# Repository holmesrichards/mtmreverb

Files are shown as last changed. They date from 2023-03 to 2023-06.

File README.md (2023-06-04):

# Spring Reverb

This is a Kosmo format adaptation of the [Music Thing Modular Spring Reverb](https://www.musicthing.co.uk/Spring-Reverb/). (Which is open source, [Creative Commons Attribution-ShareAlike 3.0](https://creativecommons.org/licenses/by-sa/3.0/), so this project is too.)

# Circuit changes

Only very minor tweaks to the original circuit:

* Expansion module (consisting of a potentiometer and a pair of RCA jacks) incorporated into main module
* Single rail-to-rail bypass caps replaced with dual rail-to-ground
* Power reversal protection diodes added
* AC coupling capacitors C1, C2 changed from 10 µF electrolytic to 1 µF film
* Footprint for 100k resistor to ground on IN_2 (FEEDBACK) left in place but marked "OMIT?"

# Discussion

R5, the 100k to ground on input IN_2, is parallel to several other ~50k resistances to ground. This means the input impedance at IN_2 is much lower than the usual 100k. R5 only makes it even lower, and I see no reason why one would want to do that. I left the footprint for this resistor in place but marked it "OMIT?" on the silkscreen and left it out in my build. This resistor is not included in the BOM.

# Errata

* In the v1.0 circuit boards the solder jumper is bridged, not open, so it should be cut if using the brick and left alone if not (contrary to what the silkscreen implies). 

* In the v1.0 front panel the pads around the hole for the "To" phono jack make the jack contact ground. This is incorrect. Use nylon washers on both sides of the hole to isolate the jack, and make sure the hole isn't plated through. 

These errors are corrected in the post-v1.0 versions.

## Current draw

 mA +12 V,  mA -12 V
 
## Photos

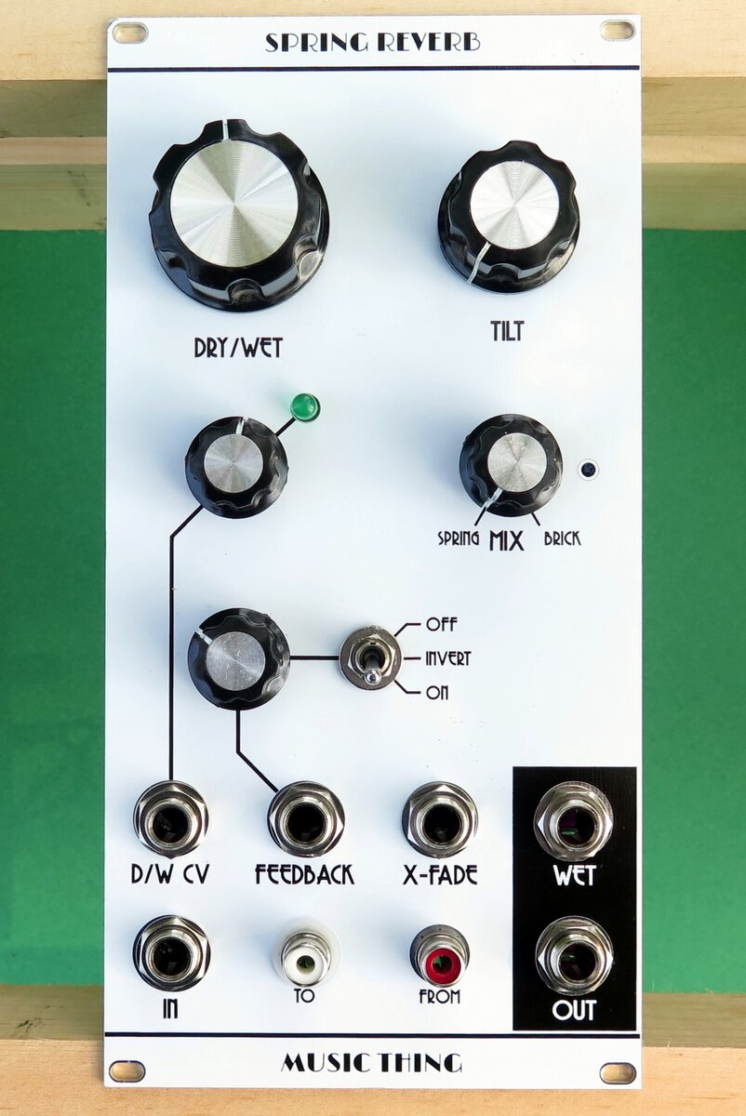
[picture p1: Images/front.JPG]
Front

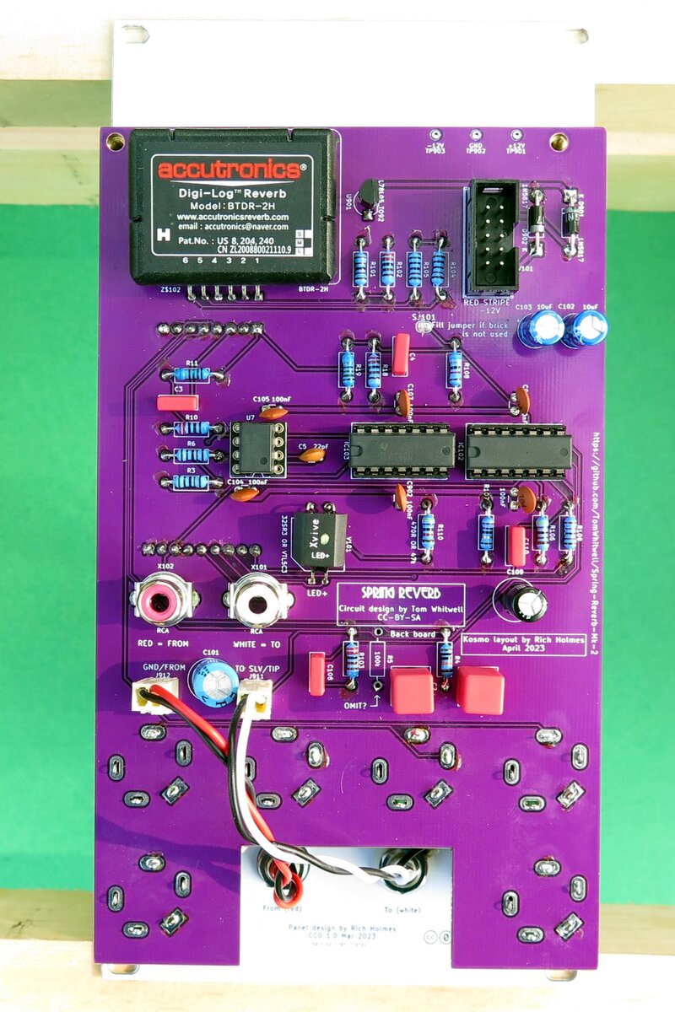
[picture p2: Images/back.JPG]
Back


## Documentation

* [Schematic](Docs/springReverbRev2_schematic.pdf)
* PCB layout: [front board front side](Docs/Layout/springReverbRev2_FrontPCB/springReverbRev2_FrontPCB_front.svg), [front board back side](Docs/Layout/springReverbRev2_FrontPCB/springReverbRev2_FrontPCB_back.svg), [back board front side](Docs/Layout/springReverbRev2_BackPCB/springReverbRev2_BackPCB_front.svg), [back board back side](Docs/Layout/springReverbRev2_BackPCB/springReverbRev2_BackPCB_back.svg)
* [BOM](Docs/BOM/springReverbRev2_bom.md)
* [Blog post](https://analogoutputblog.wordpress.com/2023/05/06/spring-has-sprung/)

## GitHub repository

* [https://github.com/holmesrichards/mtmreverb](https://github.com/holmesrichards/mtmreverb)

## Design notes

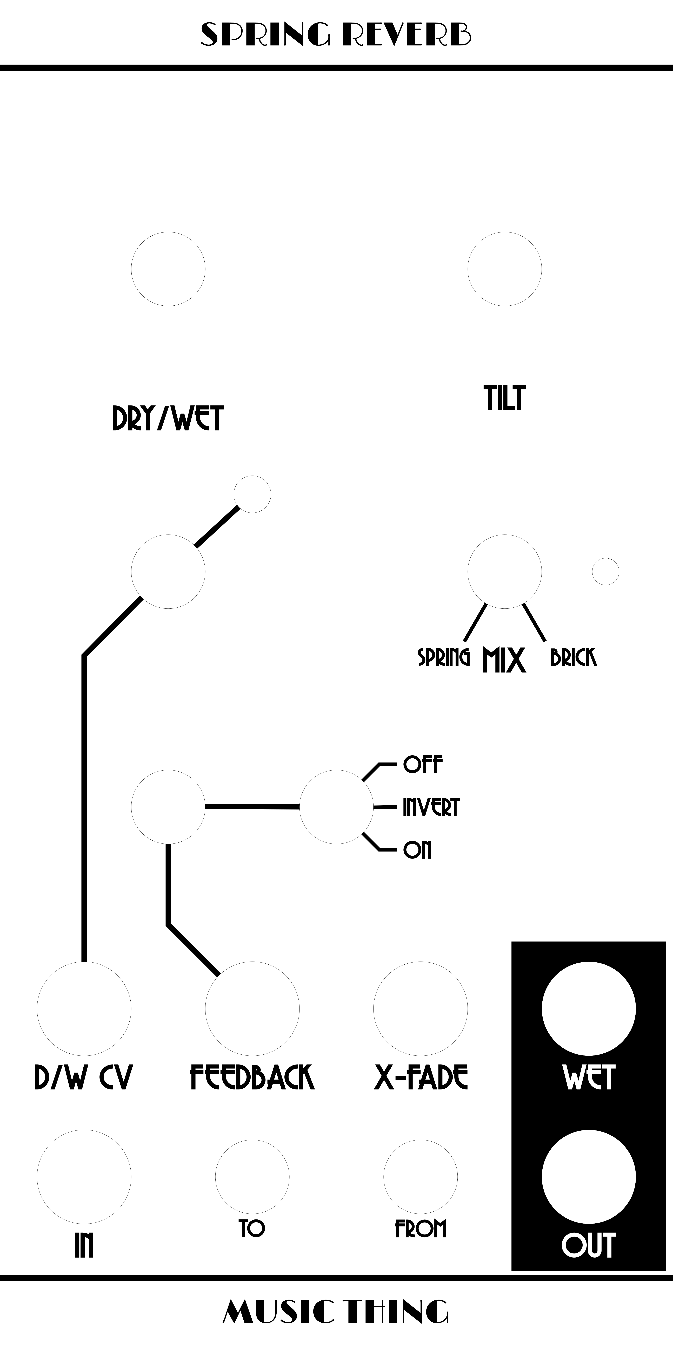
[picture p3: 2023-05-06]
Images/springreverb_panel_art.png

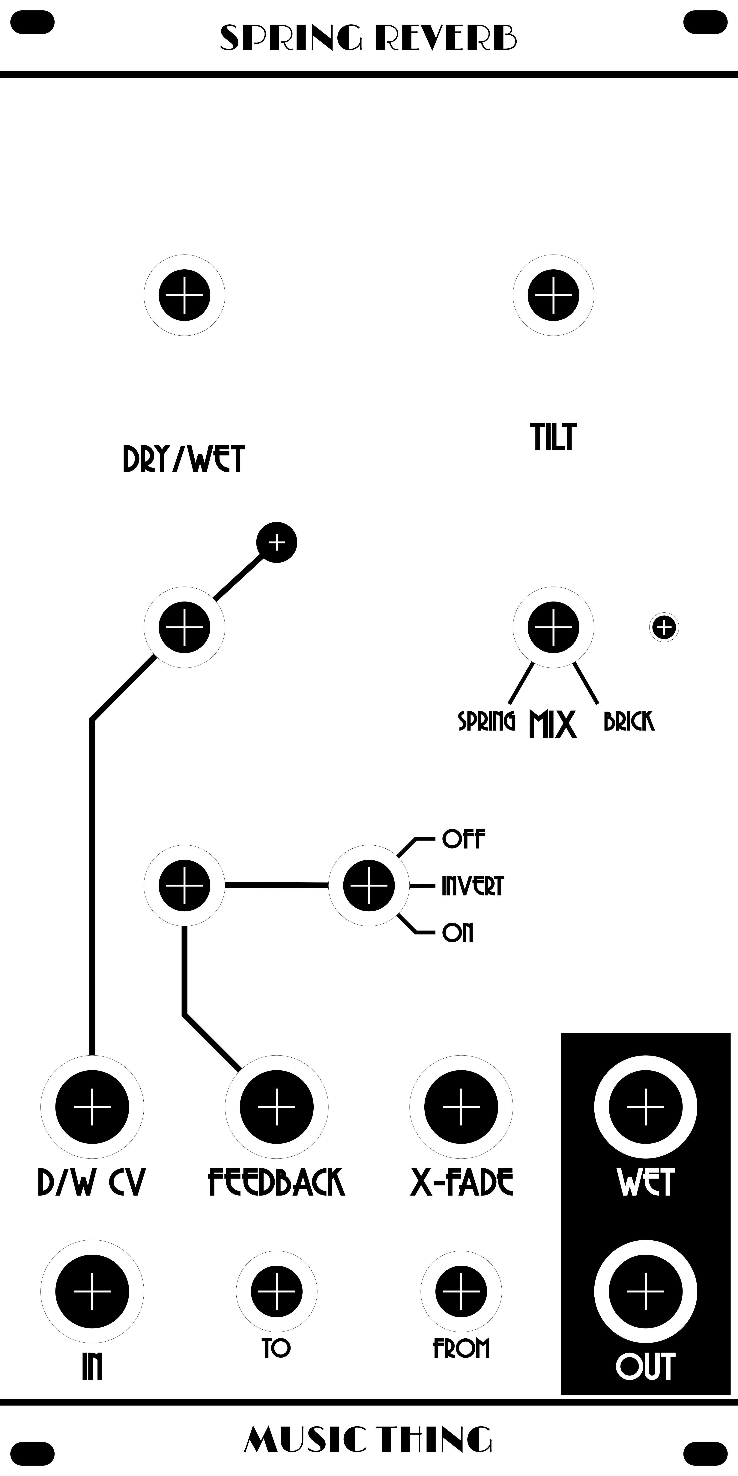
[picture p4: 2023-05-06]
Images/springreverb_panel_holes.png

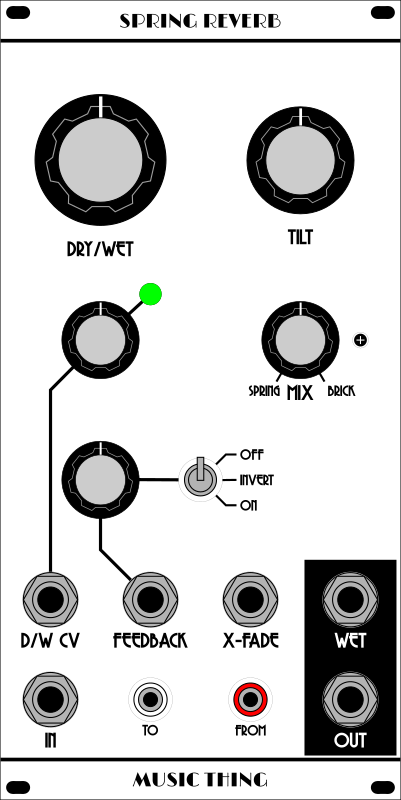
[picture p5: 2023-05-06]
Images/springreverb_panel.png

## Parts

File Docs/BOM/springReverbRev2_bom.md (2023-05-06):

# springReverbRev2.kicad_sch BOM

Fri 05 May 2023 09:01:19 PM EDT

Generated from schematic by Eeschema 7.0.2-6a45011f42~172~ubuntu22.04.1

**Component Count:** 108

| Refs | Qty | Component | Description | Manufacturer | Part | Vendor | SKU |
| ----- | --- | ---- | --- | ---- | ---- | ---- | ---- |
| C1, C2 | 2 | 1uF | Polyester film capacitor, 5 mm pitch |  |  | Tayda |  |
| C3, C4 | 2 | 33nF | Polyester film capacitor, 5 mm pitch |  |  | Tayda |  |
| C5 | 1 | 22pF | Ceramic capacitor, 2.5 mm pitch |  |  | Tayda |  |
| C6, C7, C104–107, C901–904 | 10 | 100nF | Ceramic capacitor, 2.5 mm pitch |  |  | Tayda |  |
| C101 | 1 | 10uF | Unpolarized electrolytic capacitor, 3.5 mm pitch |  |  | Tayda |  |
| C102, C103 | 2 | 10uF | Electrolytic capacitor, 2.5 mm pitch |  |  | Tayda | A-4349 |
| C108 | 1 | 3.3nF | Polyester film capacitor, 5 mm pitch |  |  | Tayda |  |
| C109 | 1 | 22uF | Unpolarized electrolytic capacitor, 3.5 mm pitch |  |  | Tayda |  |
| C110 | 1 | 2.2nF | Polyester film capacitor, 5 mm pitch |  |  | Tayda |  |
| D901, D902 | 2 | 1N5817 | Schottky Barrier Rectifier Diode, DO-41 |  |  | Tayda | A-159 |
| IC102, IC103 | 2 | TL074 | Quad operational amplifier, DIP-14 |  |  | Tayda | A-1138 |
| J901, J905 | 2 | AudioJack2_SwitchT | Audio Jack, 2 Poles (Mono / TS), Switched T Pole (Normalling) |  |  | Tayda | A-1121 |
| J902–904, J906 | 4 | AudioJack2 | Audio Jack, 2 Poles (Mono / TS) |  |  | Tayda | A-1121 |
| J907 | 1 | Conn_01x08_Socket | 2.54 mm pitch pin socket |  |  |  |  |
| J908 | 1 | Conn_01x08_Pin | 2.54 mm pitch pin header |  |  |  |  |
| J909 | 1 | Conn_01x09_Socket | 2.54 mm pitch pin socket |  |  |  |  |
| J910 | 1 | Conn_01x09_Pin | 2.54 mm pitch pin header |  |  |  |  |
| J911, J912 | 2 | 2_pin_Molex_header | KK254 Molex header |  |  | Tayda | A-804 |
| J913, J914 | 2 | 2_pin_Molex_connector | KK254 Molex connector |  |  | Tayda | A-826 |
| J915–917 | 3 | DIP-8 | 8 pin DIP socket |  |  |  |  |
| J918, J919 | 2 | DIP-14 | 14 pin DIP socket |  |  | Tayda | A-004 |
| LED1 | 1 | LED_green | Light emitting diode |  |  | Tayda | A-1553 |
| R1, R2, R7, R16, R20 | 5 | 47k | Resistor |  |  | Tayda |  |
| R3, R6, R104, R105 | 4 | 10k | Resistor |  |  | Tayda |  |
| R4, R8, R9, R12, R13, R21–23 | 8 | 100k | Resistor |  |  | Tayda |  |
| R10, R18, R24, R102, R103 | 5 | 2.2k | Resistor |  |  | Tayda |  |
| R11, R19 | 2 | 6.8k | Resistor |  |  | Tayda |  |
| R25, R101, R109 | 3 | 22k | Resistor |  |  | Tayda |  |
| R26 | 1 | 15k | Resistor |  |  | Tayda |  |
| R106 | 1 | 4.7k | Resistor |  |  | Tayda |  |
| R107 | 1 | 22R | Resistor |  |  | Tayda |  |
| R108 | 1 | 68k | Resistor |  |  | Tayda |  |
| R110 | 1 | 470R OR 47k | 470R for Silonex 32SR3, 47k for VTL5C3 |  |  | Tayda |  |
| RV901–903, RV905 | 4 | B50k | 16 mm potentiometer |  |  | Tayda |  |
| RV904 | 1 | B10k | 16 mm potentiometer |  |  | Tayda |  |
| SV101 | 1 | Synth_power_2x5 | Pin header 2.54 mm 2x5 |  |  | Tayda | A-2939 |
| SW901 | 1 | SW_SPDT_MSM | Switch, single pole double throw, center OFF position |  |  | Tayda | A-3187 |
| U1, U2 | 2 | TL072 | Dual operational amplifier, DIP-8 |  |  | Tayda | A-037 |
| U7 | 1 | NE5532 | Dual Low-Noise Operational Amplifiers, DIP-8/SOIC-8 |  |  |  |  |
| U901 | 1 | L78L05_TO92 | Positive 100mA 30V Linear Regulator, Fixed Output 5V, TO-92 |  |  | Tayda | A-176 |
| V101 | 1 | 32SR3 OR VTL5C3 | Low Cost Axial Vactrols |  |  |  |  |
| VR1 | 1 | 10k | Trim potentiometer | Bourns | 3362P | Tayda |  |
| X101 | 1 | RCA | Audio Jack, 2 Poles (Mono / TS) | CUI | RCJ-023 | Digi-Key | CP-1408-ND |
| X102 | 1 | RCA | Audio Jack, 2 Poles (Mono / TS) | CUI | RCJ-022 | Digi-Key | CP-1407-ND |
| X103 | 1 | RCA | Audio Jack, 2 Poles (Mono / TS) | Switchcraft | BPJF03X | Digi-Key | SC2441-ND |
| X104 | 1 | RCA | Audio Jack, 2 Poles (Mono / TS) | Switchcraft | BPJF02X | Digi-Key | SC2439-ND |
| Z$102 | 1 | BTDR-2H | Medium Decay Reverb Module | Belton Accutronics | BTDR-2H |  |  |
| ZKN901 | 1 | Knob_MF-A04 | MF-A04 knob |  |  |  |  |
| ZKN902 | 1 | Knob_MF-A03 | MF-A03 knob |  |  |  |  |
| ZKN903–905 | 3 | Knob_MF-A01 | MF-A01 knob |  |  |  |  |
| ZSC901–904 | 4 | Screw | M3 6 mm screw |  |  |  |  |
| ZSP901, ZSP902 | 2 | Spacer | M3 10 mm FF spacer |  |  |  |  |
| ZWA901, ZWA902 | 2 | Washer | M3 washer |  |  |  |  |

## Resistors in color band order
|Value|Qty|Refs|
|----|----|----|
|10k|4|R3, R6, R104, R105|
|100k|8|R4, R8, R9, R12, R13, R21–23|
|15k|1|R26|
|22R|1|R107|
|2.2k|5|R10, R18, R24, R102, R103|
|22k|3|R25, R101, R109|
|4.7k|1|R106|
|47k|5|R1, R2, R7, R16, R20|
|6.8k|2|R11, R19|
|68k|1|R108|
|470R OR 47k|1|R110|

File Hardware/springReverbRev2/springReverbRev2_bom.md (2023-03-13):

# springReverbRev2.kicad_sch BOM

Wed 08 Mar 2023 10:55:59 PM EST

Generated from schematic by Eeschema 7.0.0-da2b9df05c~171~ubuntu22.04.1

**Component Count:** 109

| Refs | Qty | Component | Description | Manufacturer | Part | Vendor | SKU |
| ----- | --- | ---- | --- | ---- | ---- | ---- | ---- |
| C1, C2, C101 | 3 | 10uF | Unpolarized electrolytic capacitor |  |  | Tayda |  |
| C3, C4 | 2 | 33nF | Polyester film capacitor |  |  | Tayda |  |
| C5 | 1 | 22pF | Ceramic capacitor |  |  | Tayda |  |
| C6, C7, C104–107, C901–904 | 10 | 100nF | Ceramic capacitor |  |  | Tayda |  |
| C102, C103 | 2 | 10uF | Electrolytic capacitor, 2.5 mm pitch |  |  | Tayda | A-4349 |
| C108 | 1 | 3.3nF | Polyester film capacitor |  |  | Tayda |  |
| C109 | 1 | 22uF | Unpolarized electrolytic capacitor |  |  | Tayda |  |
| C110 | 1 | 2.2nF | Polyester film capacitor |  |  | Tayda |  |
| D901, D902 | 2 | 1N5817 | Schottky Barrier Rectifier Diode, DO-41 |  |  | Tayda | A-159 |
| IC102, IC103 | 2 | TL074 | Quad operational amplifier, DIP-14 |  |  | Tayda | A-1138 |
| J901, J905 | 2 | AudioJack2_SwitchT | Audio Jack, 2 Poles (Mono / TS), Switched T Pole (Normalling) |  |  | Tayda | A-1121 |
| J902–904, J906 | 4 | AudioJack2 | Audio Jack, 2 Poles (Mono / TS) |  |  | Tayda | A-1121 |
| J907 | 1 | Conn_01x08_Socket | Generic connector, single row, 01x08, script generated |  |  |  |  |
| J908 | 1 | Conn_01x08_Pin | Generic connector, single row, 01x08, script generated |  |  |  |  |
| J909 | 1 | Conn_01x09_Socket | Generic connector, single row, 01x09, script generated |  |  |  |  |
| J910 | 1 | Conn_01x09_Pin | Generic connector, single row, 01x09, script generated |  |  |  |  |
| J911, J912 | 2 | 2_pin_Molex_header | KK254 Molex header |  |  | Tayda | A-804 |
| J913, J914 | 2 | 2_pin_Molex_connector | KK254 Molex connector |  |  | Tayda | A-826 |
| J915–917 | 3 | DIP-8 | 8 pin DIP socket |  |  |  |  |
| J918, J919 | 2 | DIP-14 | 14 pin DIP socket |  |  |  |  |
| LED1 | 1 | LED_green | Light emitting diode |  |  | Tayda | A-1553 |
| R1, R2, R7, R16, R20 | 5 | 47k | Resistor |  |  | Tayda |  |
| R3, R6, R104, R105 | 4 | 10k | Resistor |  |  | Tayda |  |
| R8, R9, R12, R13, R21–23, R901, R902 | 9 | 100k | Resistor |  |  | Tayda |  |
| R10, R18, R24, R102, R103 | 5 | 2.2k | Resistor |  |  | Tayda |  |
| R11, R19 | 2 | 6.8k | Resistor |  |  | Tayda |  |
| R25, R101, R109 | 3 | 22k | Resistor |  |  | Tayda |  |
| R26 | 1 | 15k | Resistor |  |  | Tayda |  |
| R106 | 1 | 4.7k | Resistor |  |  | Tayda |  |
| R107 | 1 | 22R | Resistor |  |  | Tayda |  |
| R108 | 1 | 68k | Resistor |  |  | Tayda |  |
| R110 | 1 | 470R OR 47k | Resistor |  |  | Tayda |  |
| RV901–903, RV905 | 4 | B50k | Potentiometer |  |  | Tayda |  |
| RV904 | 1 | B10k | Potentiometer |  |  | Tayda |  |
| SV101 | 1 | Synth_power_2x5 | Pin header 2.54 mm 2x5 |  |  | Tayda | A-2939 |
| SW901 | 1 | SW_SPDT_MSM | Switch, single pole double throw, center OFF position |  |  | Tayda | A-3187 |
| U1, U2 | 2 | TL072 | Dual operational amplifier, DIP-8 |  |  | Tayda | A-037 |
| U7 | 1 | NE5532 | Dual Low-Noise Operational Amplifiers, DIP-8/SOIC-8 |  |  |  |  |
| U901 | 1 | L78L05_TO92 | Positive 100mA 30V Linear Regulator, Fixed Output 5V, TO-92 |  |  | Tayda | A-176 |
| V101 | 1 | 32SR3 OR VTL5C3 | Low Cost Axial Vactrols |  |  |  |  |
| VR1 | 1 | 10k | Trim-potentiometer |  |  | Tayda |  |
| X101 | 1 | RCA | Audio Jack, 2 Poles (Mono / TS) | CUI | RCJ-023 | Digi-Key | CP-1408-ND |
| X102 | 1 | RCA | Audio Jack, 2 Poles (Mono / TS) | CUI | RCJ-022 | Digi-Key | CP-1407-ND |
| X103 | 1 | RCA | Audio Jack, 2 Poles (Mono / TS) | Switchcraft | BPJF03X | Digi-Key | SC2441-ND |
| X104 | 1 | RCA | Audio Jack, 2 Poles (Mono / TS) | Switchcraft | BPJF02X | Digi-Key | SC2439-ND |
| Z$102 | 1 | BTDR-2H |  |  |  |  |  |
| ZKN901 | 1 | Knob_MF-A04 | MF-A04 knob |  |  |  |  |
| ZKN902 | 1 | Knob_MF-A03 | MF-A03 knob |  |  |  |  |
| ZKN903–905 | 3 | Knob_MF-A01 | MF-A01 knob |  |  |  |  |
| ZSC901–904 | 4 | Screw | M3 6 mm screw |  |  |  |  |
| ZSP901, ZSP902 | 2 | Spacer | M3 10 mm FF spacer |  |  |  |  |
| ZWA901, ZWA902 | 2 | Washer | M3 washer |  |  |  |  |

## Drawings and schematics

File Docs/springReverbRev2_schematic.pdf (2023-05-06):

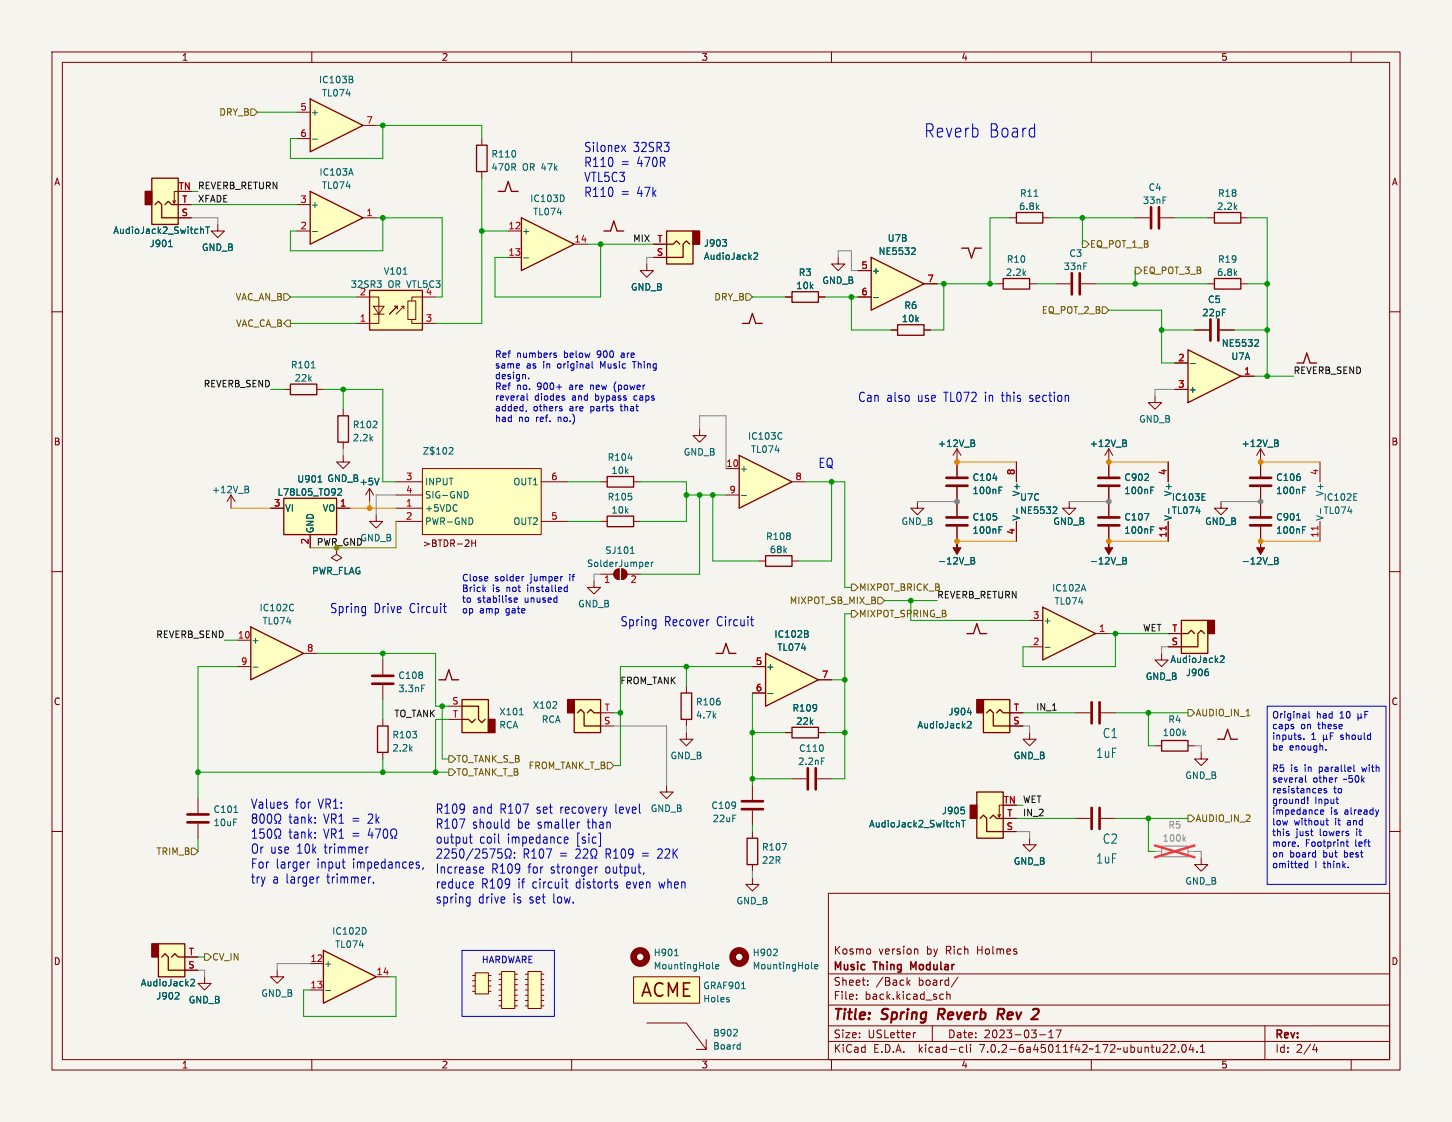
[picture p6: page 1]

op amp gate Ref numbers below 900 are

design. Ref no. 900+ are new (power

reveral diodes and bypass caps added, others are parts that had no ref. no.)

Close solder jumper if Brick is not installed

several other ~50k
ground! Input
low without it and

Values for VR1:
þÿ800©tank: VR1 = 2k
þÿ150©tank: VR1 = þÿ470©
Or use 10k trimmer
For larger input impedances,

R109 and R107 set recovery level
R107 should be smaller than
output coil impedance [sic]
Increase R109 for stronger output,
reduce R109 if circuit distorts even when
spring drive is set low.

Id: 2/4 Title: Spring Reverb Rev 2

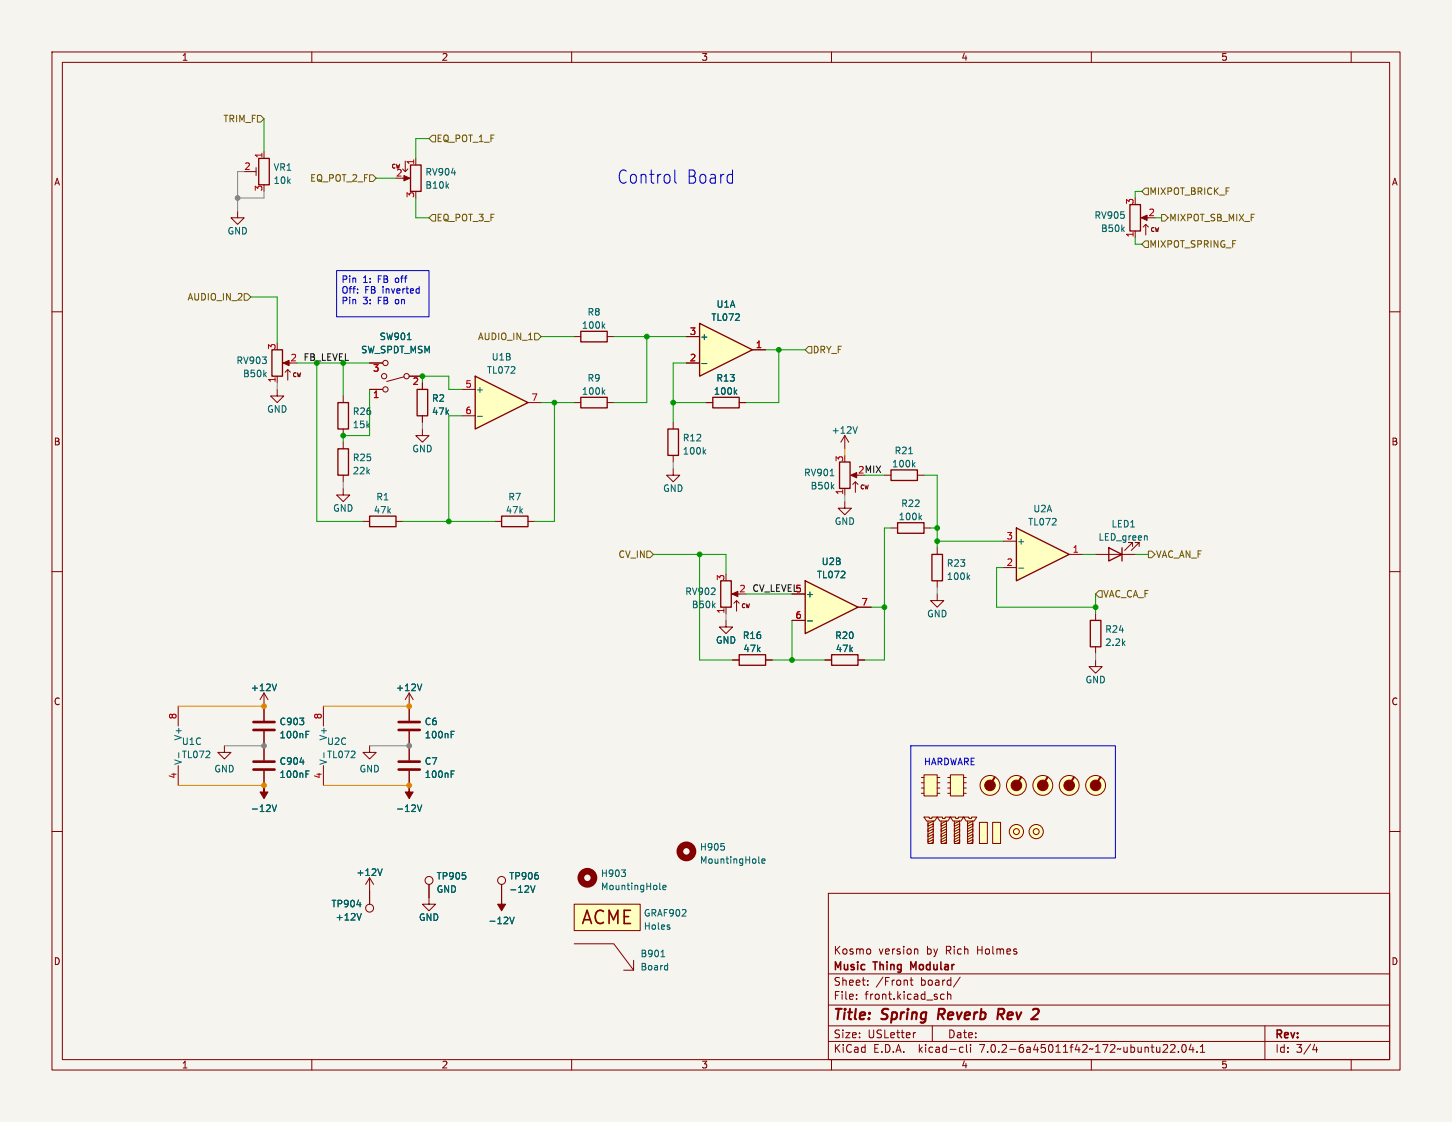
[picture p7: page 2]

Id: 3/4 Title: Spring Reverb Rev 2

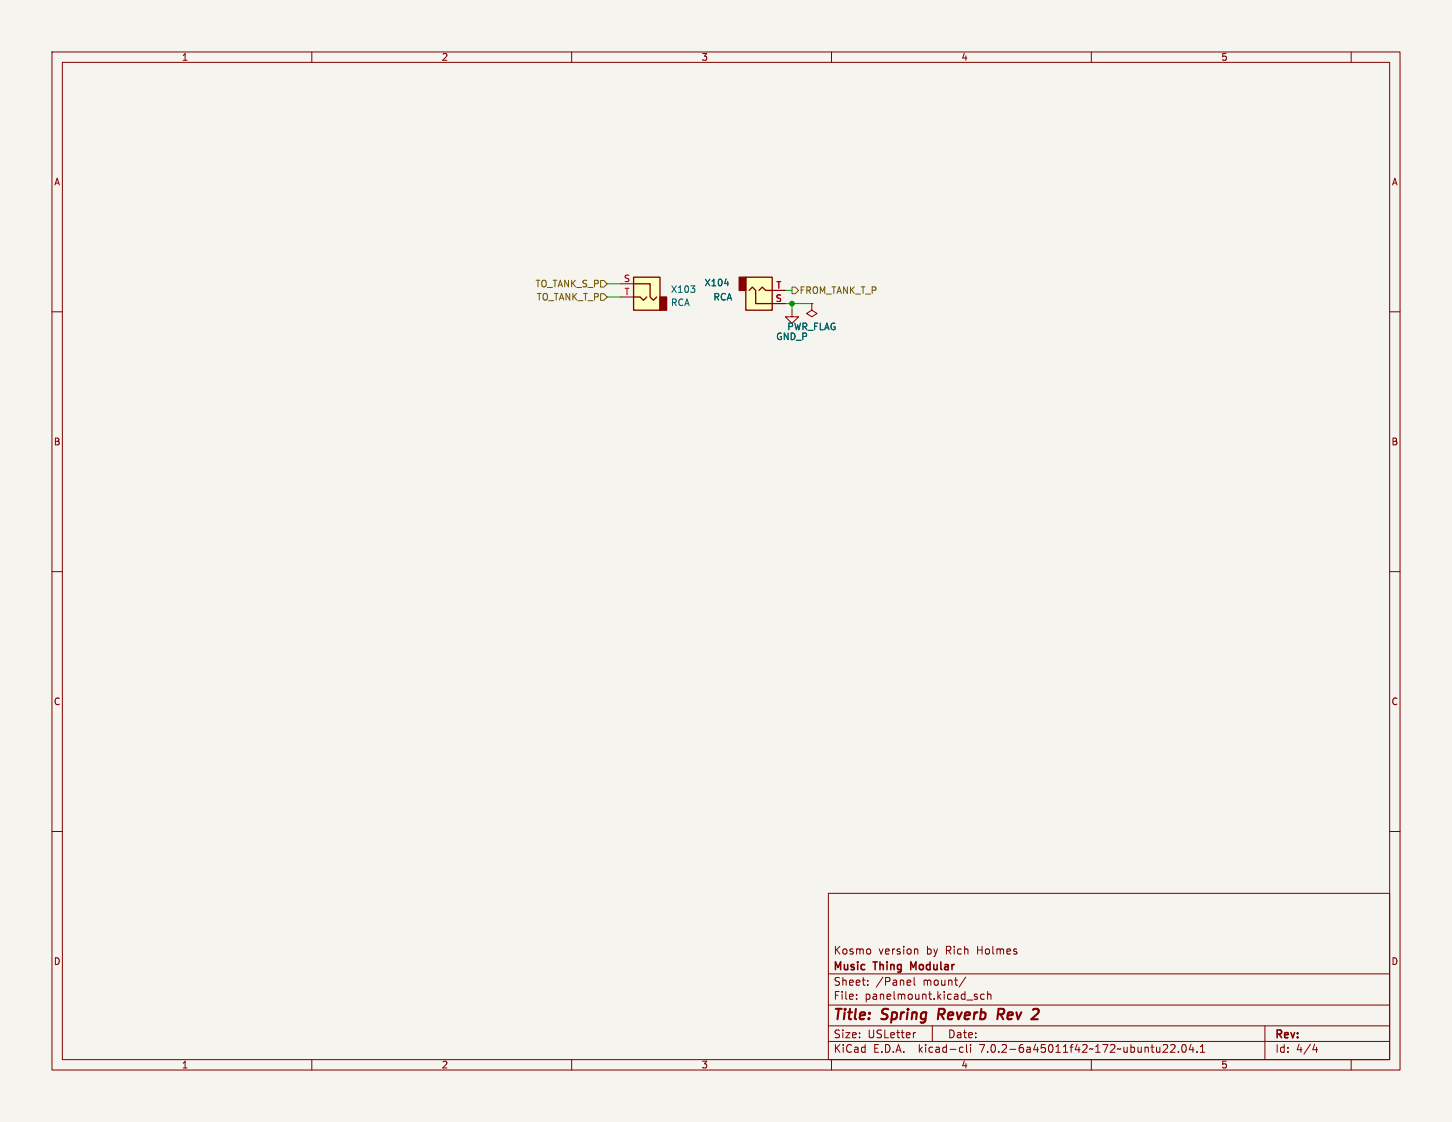
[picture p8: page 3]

Id: 4/4 Title: Spring Reverb Rev 2

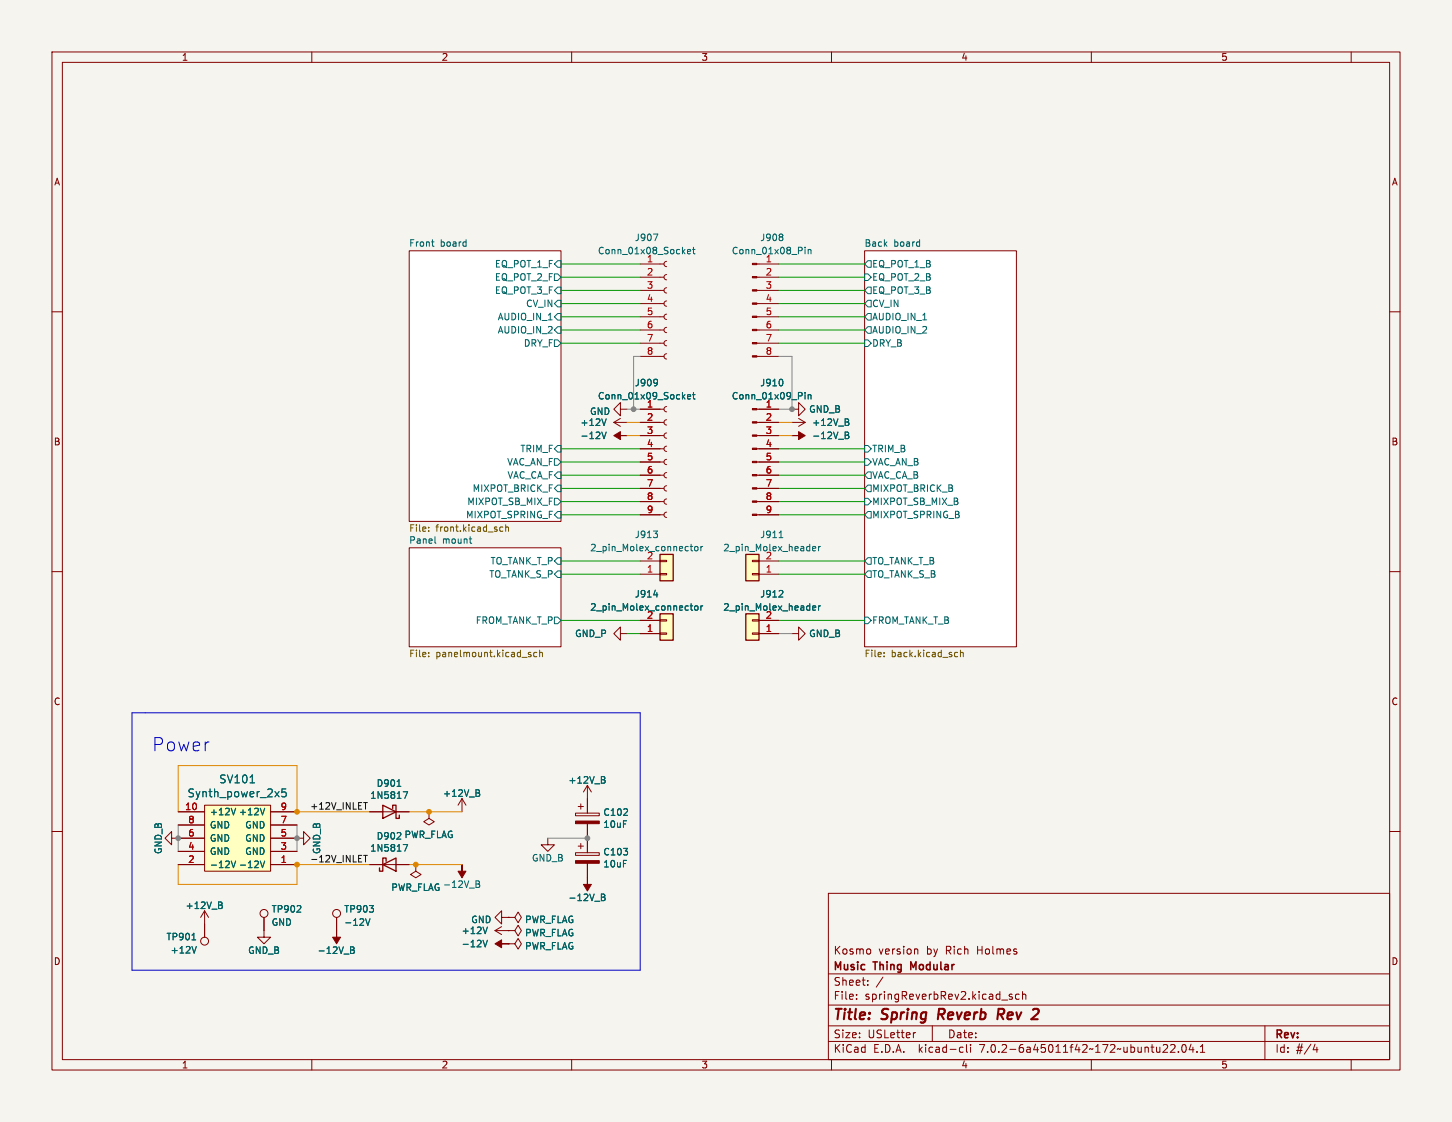
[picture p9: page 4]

Back board File: back.kicad_sch TO_TANK_S_P

Panel mount File: panelmount.kicad_sch

Id: #/4 Title: Spring Reverb Rev 2

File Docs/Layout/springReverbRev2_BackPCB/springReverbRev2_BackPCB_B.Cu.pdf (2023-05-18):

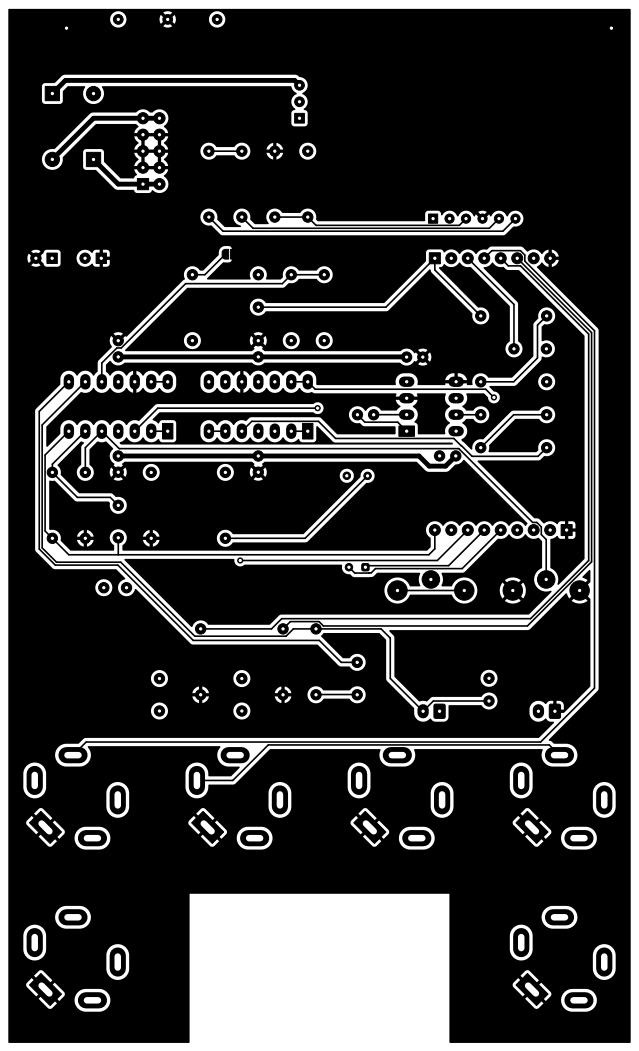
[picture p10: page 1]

Id: 1/1 Title: Spring Reverb Rev 2

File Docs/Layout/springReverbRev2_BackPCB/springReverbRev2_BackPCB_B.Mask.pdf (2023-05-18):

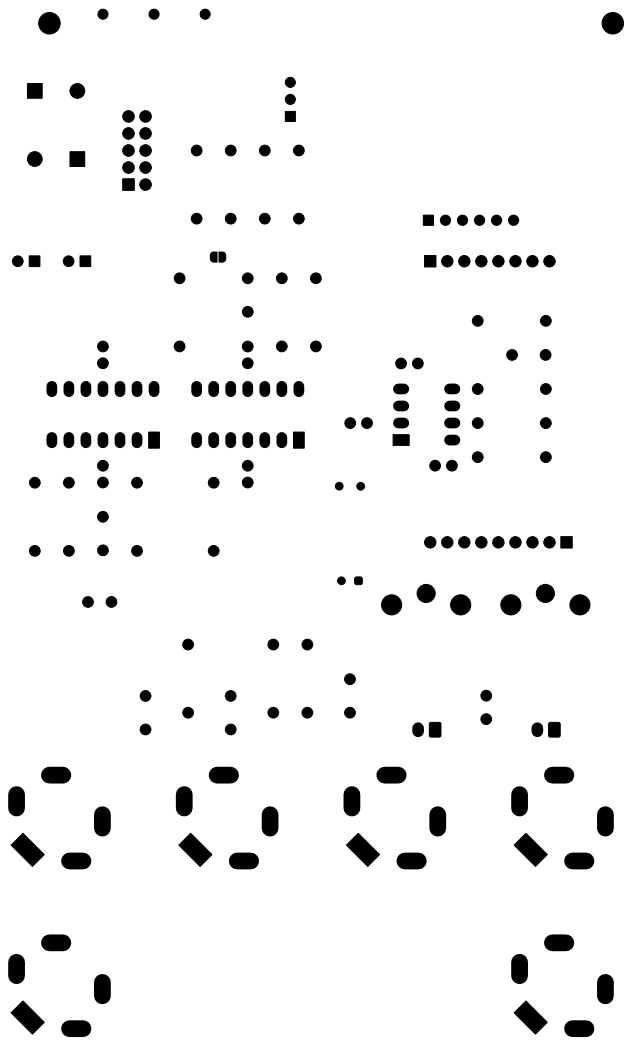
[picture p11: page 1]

Id: 1/1 Title: Spring Reverb Rev 2

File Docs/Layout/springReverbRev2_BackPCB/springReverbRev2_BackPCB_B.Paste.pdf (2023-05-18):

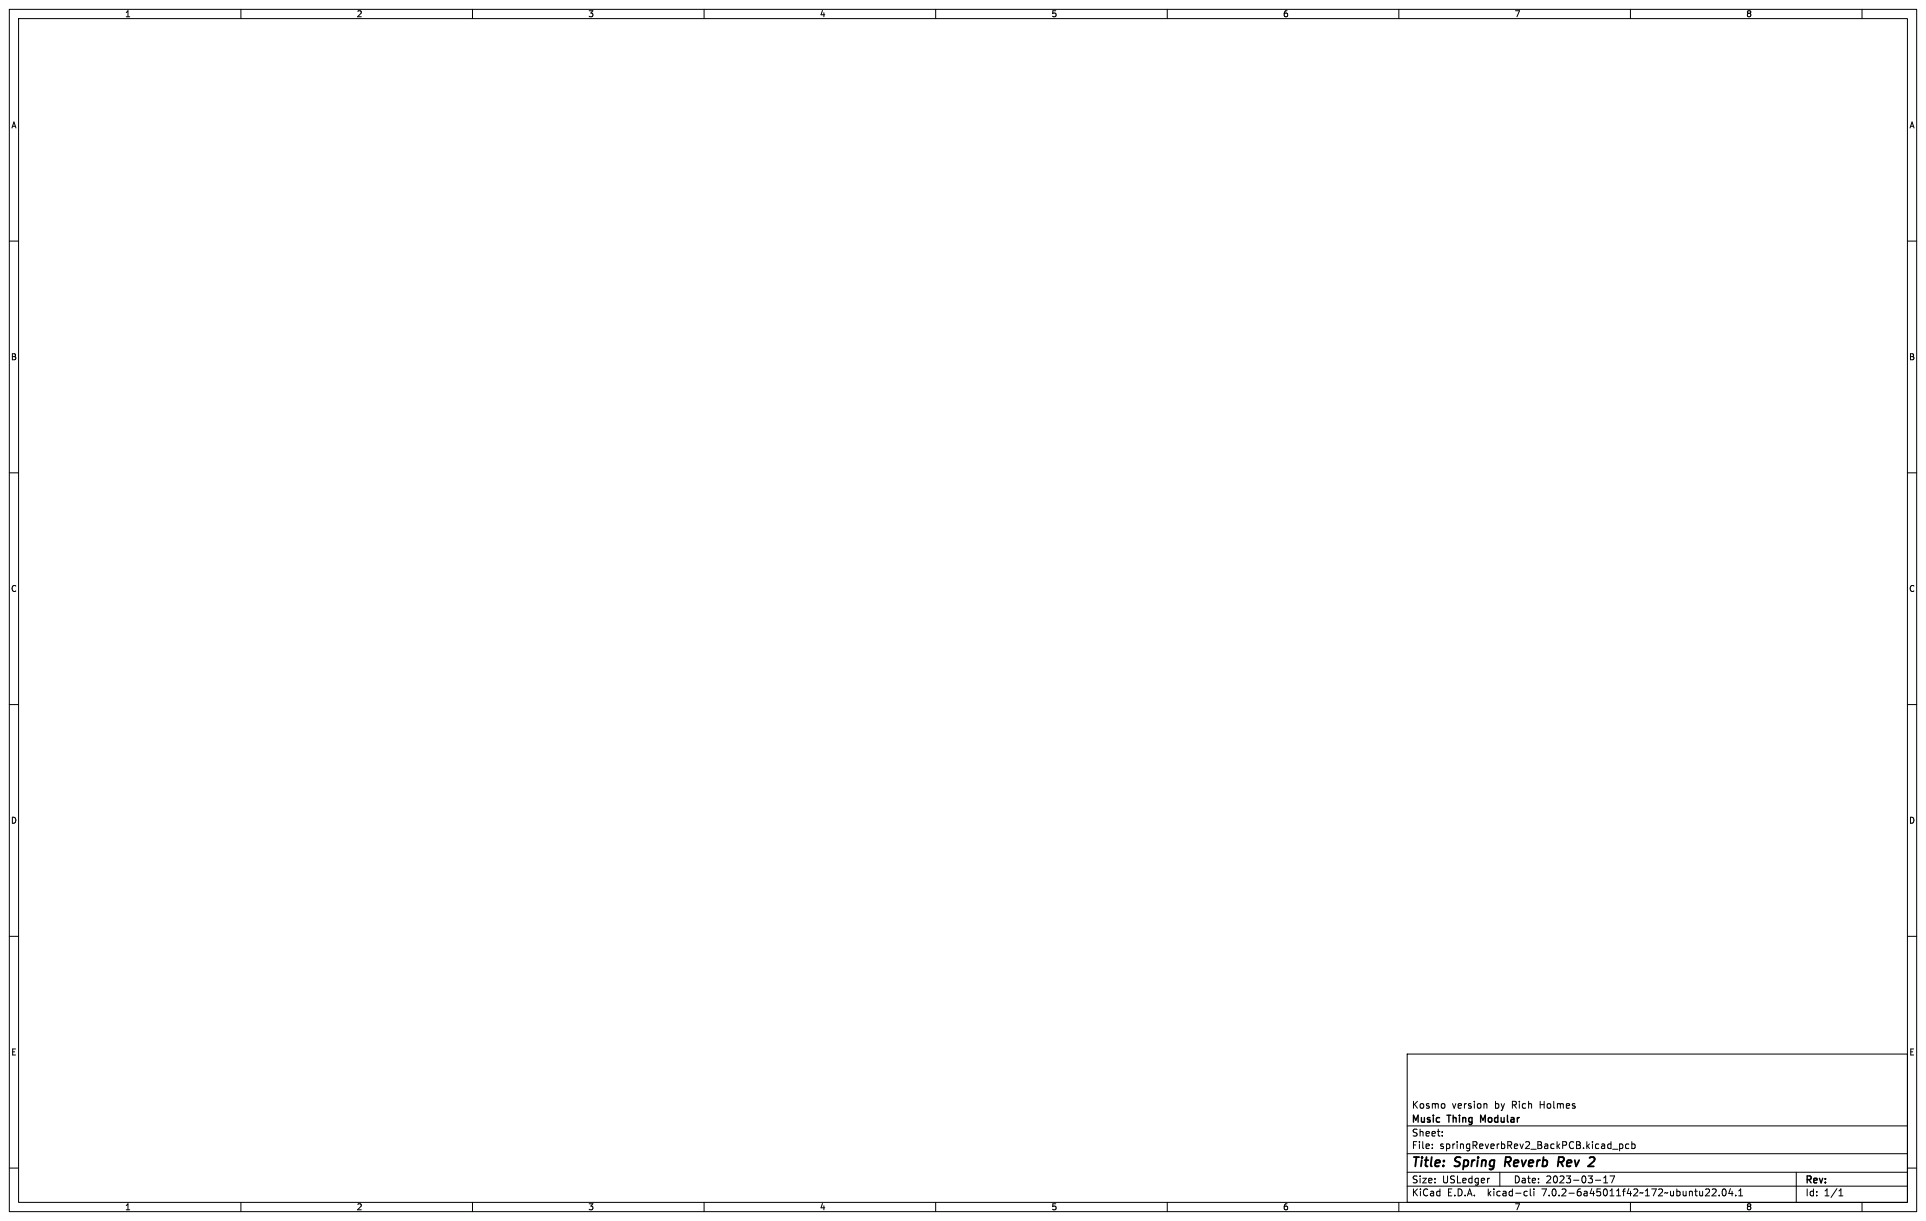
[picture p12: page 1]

Id: 1/1 Title: Spring Reverb Rev 2

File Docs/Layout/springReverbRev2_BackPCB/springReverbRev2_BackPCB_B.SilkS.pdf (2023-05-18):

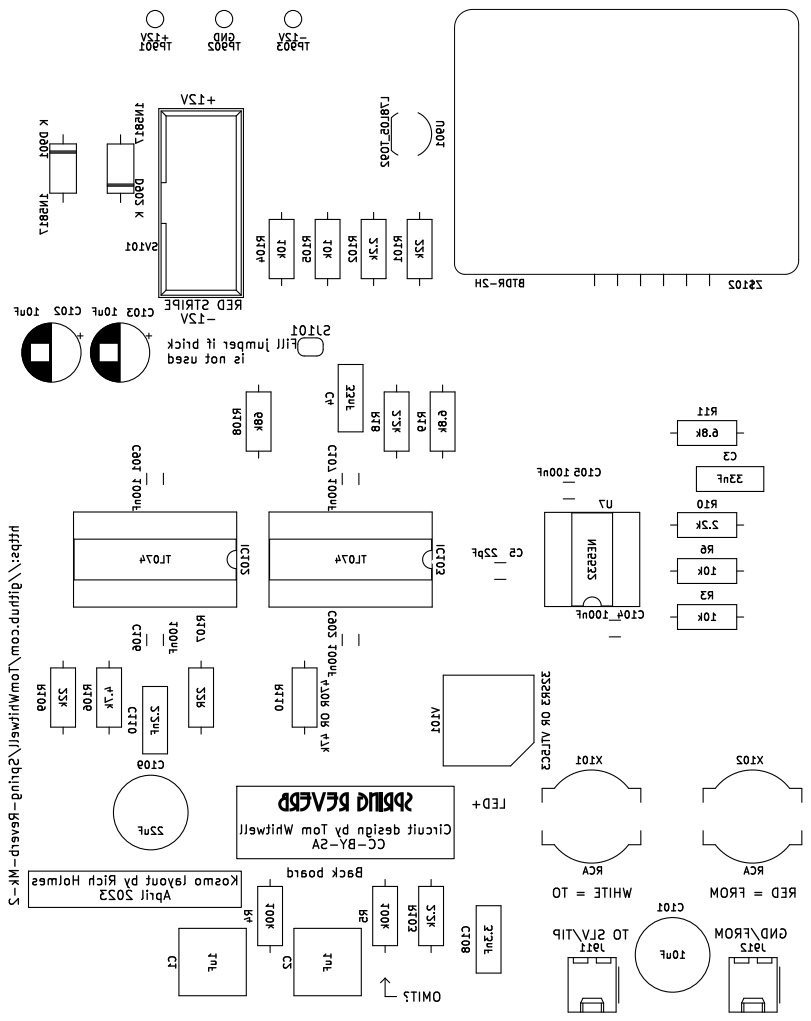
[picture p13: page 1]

Fill jumper if brick

Id: 1/1 Title: Spring Reverb Rev 2

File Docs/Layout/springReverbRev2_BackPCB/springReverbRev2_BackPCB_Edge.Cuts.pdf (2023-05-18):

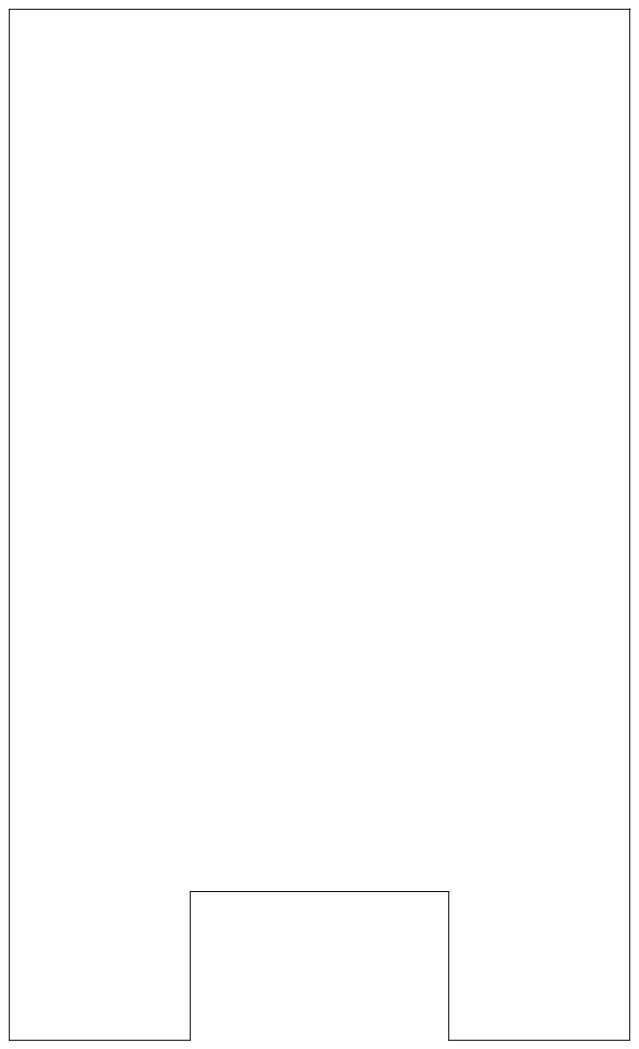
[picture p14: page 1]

Id: 1/1 Title: Spring Reverb Rev 2

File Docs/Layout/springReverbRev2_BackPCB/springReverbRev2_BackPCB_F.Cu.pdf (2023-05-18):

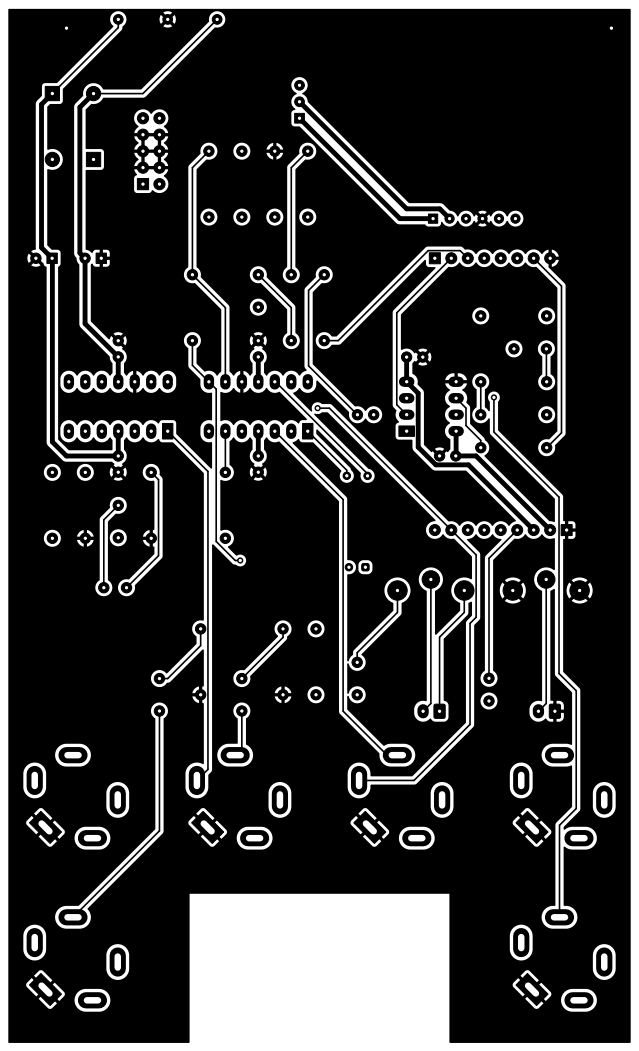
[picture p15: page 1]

Id: 1/1 Title: Spring Reverb Rev 2

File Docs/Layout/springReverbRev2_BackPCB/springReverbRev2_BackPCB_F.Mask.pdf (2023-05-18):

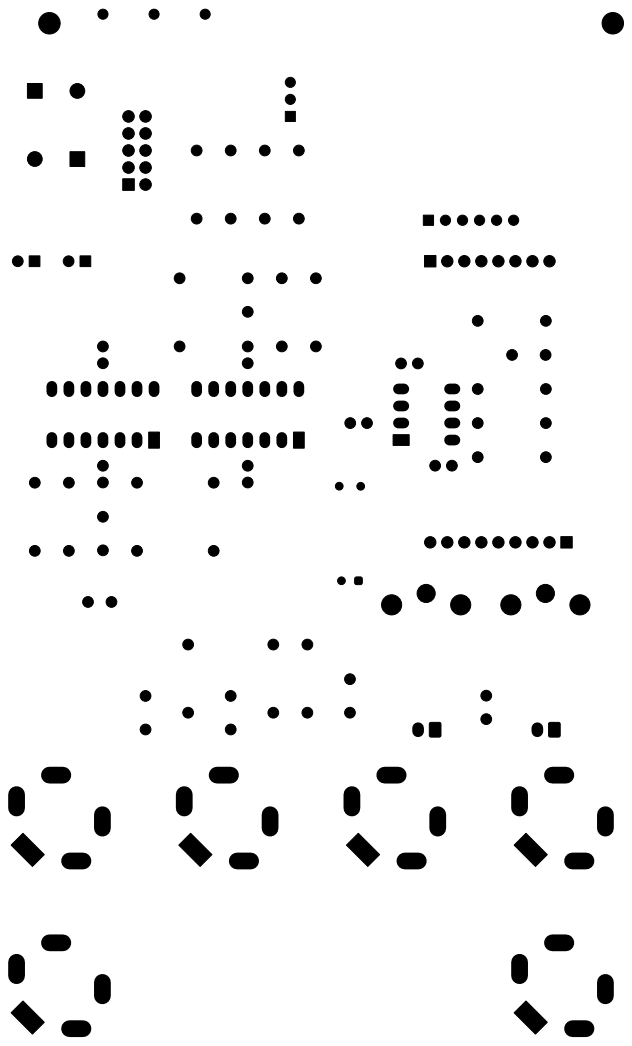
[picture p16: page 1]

Id: 1/1 Title: Spring Reverb Rev 2

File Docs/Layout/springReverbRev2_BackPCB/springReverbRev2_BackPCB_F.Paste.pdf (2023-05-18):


Id: 1/1 Title: Spring Reverb Rev 2

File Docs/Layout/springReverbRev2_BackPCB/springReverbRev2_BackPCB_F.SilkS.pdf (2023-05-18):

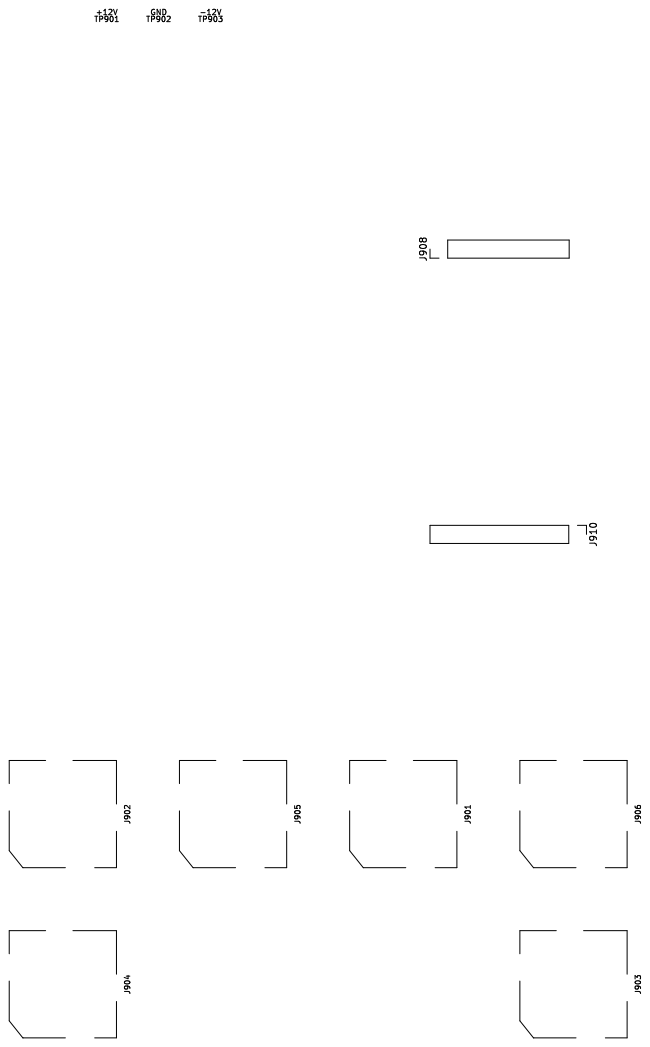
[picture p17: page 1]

Id: 1/1 Title: Spring Reverb Rev 2

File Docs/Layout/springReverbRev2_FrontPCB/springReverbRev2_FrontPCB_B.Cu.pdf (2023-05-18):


Id: 1/1 Title: Spring Reverb Rev 2

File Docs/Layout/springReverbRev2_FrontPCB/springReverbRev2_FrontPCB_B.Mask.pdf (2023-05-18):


Id: 1/1 Title: Spring Reverb Rev 2

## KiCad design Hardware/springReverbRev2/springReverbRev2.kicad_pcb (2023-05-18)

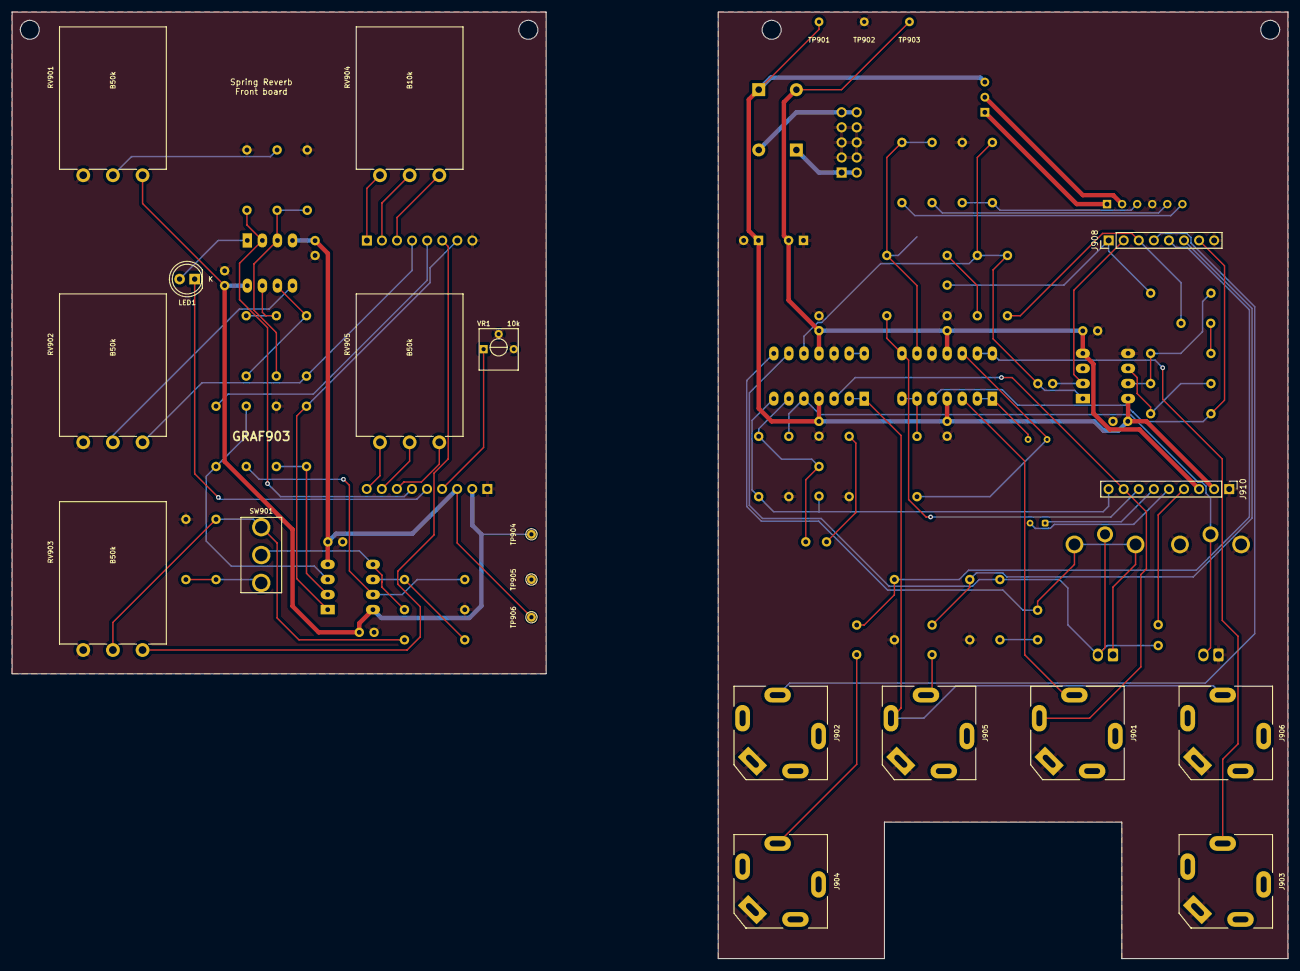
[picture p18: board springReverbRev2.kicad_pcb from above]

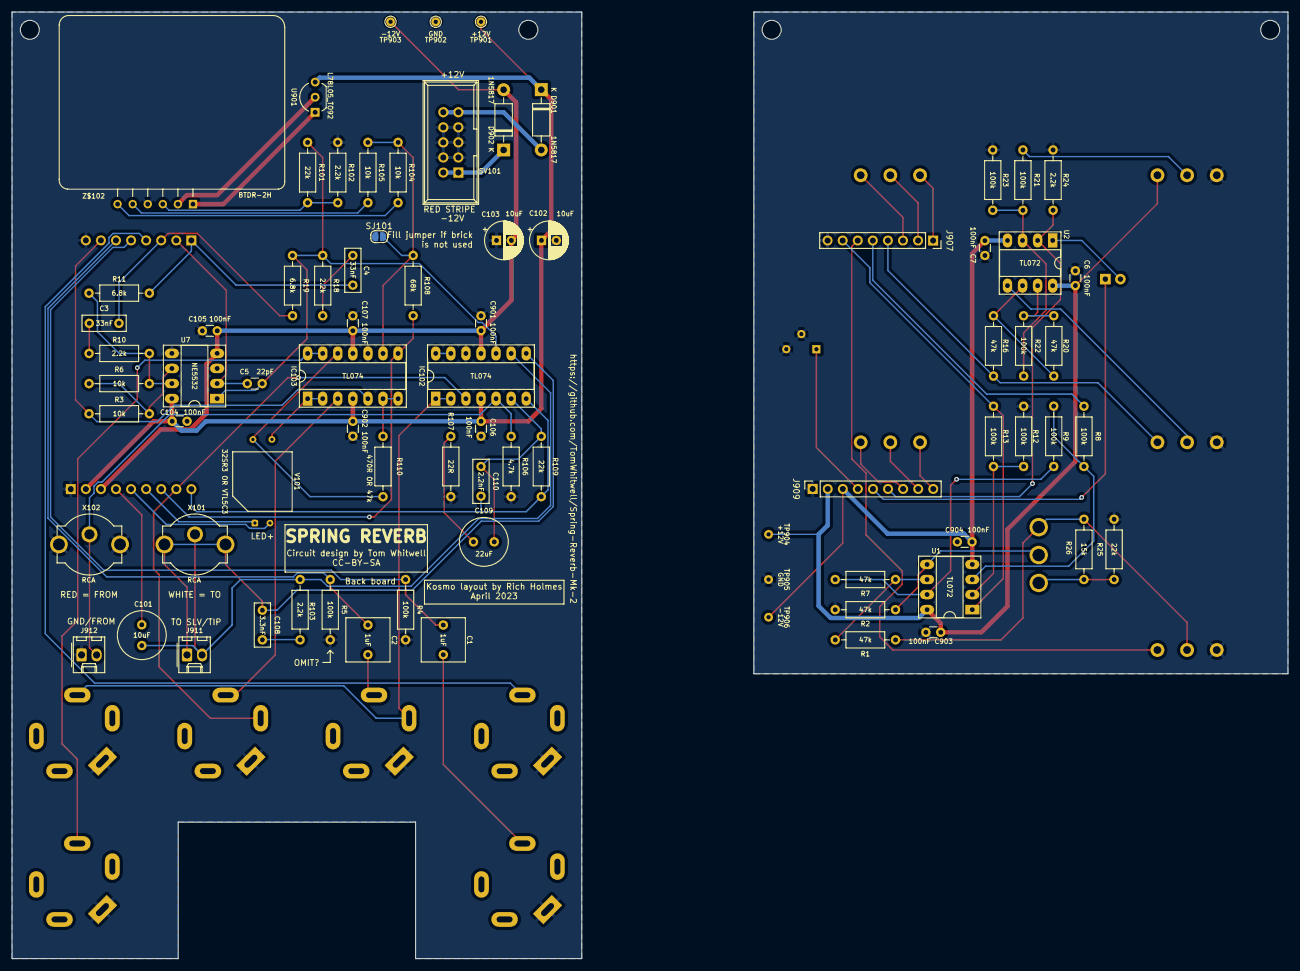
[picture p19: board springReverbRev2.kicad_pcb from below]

Board: 2 copper layers, 215.0 x 159.5 mm, 103 parts (75 on the bottom side), 73 nets.

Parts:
B901, B902: Board; Board_Marker
C1, C2: 1uF; C_Rect_L7.2mm_W7.2mm_P5.00mm_FKS2_FKP2_MKS2_MKP2
C3, C4: 33nF; C_Rect_L7.2mm_W2.5mm_P5.00mm_FKS2_FKP2_MKS2_MKP2
C5: 22pF; C_Disc_D3.0mm_W1.6mm_P2.50mm
C6, C7, C104, C105, C106, C107, C901, C902, C903, C904: 100nF; C_Disc_D3.0mm_W1.6mm_P2.50mm
C101: 10uF; C_Radial_D8.0mm_H11.5mm_P3.50mm
C102, C103: 10uF; CP_Radial_D6.3mm_P2.50mm
C108: 3.3nF; C_Rect_L7.2mm_W2.5mm_P5.00mm_FKS2_FKP2_MKS2_MKP2
C109: 22uF; C_Radial_D8.0mm_H11.5mm_P3.50mm
C110: 2.2nF; C_Rect_L7.2mm_W2.5mm_P5.00mm_FKS2_FKP2_MKS2_MKP2
D901, D902: 1N5817; D_DO-41_SOD81_P10.16mm_Horizontal
GRAF901, GRAF902: Holes; springreverb_panel_holes
GRAF903: Holes; springreverb_panel_holes2
H901, H902, H903, H905: MountingHole; MountingHole_3.2mm_M3
IC102, IC103: TL074; DIP-14_W7.62mm_Socket_LongPads
J901, J905: AudioJack2_SwitchT; Jack_6.35mm_PJ_629HAN_slots
J902, J903, J904, J906: AudioJack2; Jack_6.35mm_PJ_629HAN_slots
J907: Conn_01x08_Socket; PinSocket_1x08_P2.54mm_Vertical
J908: Conn_01x08_Pin; PinHeader_1x08_P2.54mm_Vertical
J909: Conn_01x09_Socket; PinSocket_1x09_P2.54mm_Vertical
J910: Conn_01x09_Pin; PinHeader_1x09_P2.54mm_Vertical
J911, J912: 2_pin_Molex_header; Molex_KK-254_AE-6410-02A_1x02_P2.54mm_Vertical
LED1: LED_green; LED_D5.0mm
R1, R2, R7, R16, R20: 47k; R_Axial_DIN0207_L6.3mm_D2.5mm_P10.16mm_Horizontal
R3, R6, R104, R105: 10k; R_Axial_DIN0207_L6.3mm_D2.5mm_P10.16mm_Horizontal
R4, R5, R8, R9, R12, R13, R21, R22, R23: 100k; R_Axial_DIN0207_L6.3mm_D2.5mm_P10.16mm_Horizontal
R10, R18, R24, R102, R103: 2.2k; R_Axial_DIN0207_L6.3mm_D2.5mm_P10.16mm_Horizontal
R11, R19: 6.8k; R_Axial_DIN0207_L6.3mm_D2.5mm_P10.16mm_Horizontal
R25, R101, R109: 22k; R_Axial_DIN0207_L6.3mm_D2.5mm_P10.16mm_Horizontal
R26: 15k; R_Axial_DIN0207_L6.3mm_D2.5mm_P10.16mm_Horizontal
R106: 4.7k; R_Axial_DIN0207_L6.3mm_D2.5mm_P10.16mm_Horizontal
R107: 22R; R_Axial_DIN0207_L6.3mm_D2.5mm_P10.16mm_Horizontal
R108: 68k; R_Axial_DIN0207_L6.3mm_D2.5mm_P10.16mm_Horizontal
R110: 470R OR 47k; R_Axial_DIN0207_L6.3mm_D2.5mm_P10.16mm_Horizontal
RV901, RV902, RV903, RV905: B50k; Potentiometer_Alpha_16mm_Single_Vertical
RV904: B10k; Potentiometer_Alpha_16mm_Single_Vertical
SJ101: SolderJumper; SolderJumper-2_P1.3mm_Open_RoundedPad1.0x1.5mm
SV101: Synth_power_2x5; Power_Header
SW901: SW_SPDT_MSM; SPDT-toggle-switch-1M-series
TP901, TP904: +12V; TestPoint_THTPad_D1.5mm_Drill0.7mm
TP902, TP905: GND; TestPoint_THTPad_D1.5mm_Drill0.7mm
TP903, TP906: -12V; TestPoint_THTPad_D1.5mm_Drill0.7mm
U1, U2: TL072; DIP-8_W7.62mm_Socket_LongPads
U7: NE5532; DIP-8_W7.62mm_Socket_LongPads
U901: L78L05_TO92; TO-92_Inline_Wide
V101: 32SR3 OR VTL5C3; Vactrol_VTL5C
VR1: 10k; Potentiometer_Bourns_3362P_Vertical_screw_centered
X101: RCA; RCJ-023 white
X102: RCA; RCJ-022 red
Z$102: BTDR-2H

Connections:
+5V: U901.1 (VO), Z$102.1 (+5VDC)
+12V: C6.1, C903.1, J909.2, RV901.3, TP904.1, U1.8 (V+), U2.8 (V+)
+12V_B: C102.1, C104.1, C106.1, C902.1, D901.1 (K), IC102.4 (V+), IC103.4 (V+), J910.2, TP901.1, U7.8 (V+), U901.3 (VI)
-12V: C7.2, C904.2, J909.3, TP906.1, U1.4 (V-), U2.4 (V-)
-12V_B: C103.2, C105.2, C107.2, C901.2, D902.2 (A), IC102.11 (V-), IC103.11 (V-), J910.3, TP903.1, U7.4 (V-)
/+12V_INLET: D901.2 (A), SV101.9 (+12V), SV101.10 (+12V)
/-12V_INLET: D902.1 (K), SV101.1 (-12V), SV101.2 (-12V)
/Back board/AUDIO_IN_1: C1.1, J908.5, R4.1
/Back board/AUDIO_IN_2: C2.1, J908.6, R5.1
/Back board/CV_IN: J902.T, J908.4
/Back board/DRY_B: IC103.5 (+), J908.7, R3.1
/Back board/EQ_POT_1_B: C4.1, J908.1, R11.2
/Back board/EQ_POT_2_B: C5.1, J908.2, U7.2 (-)
/Back board/EQ_POT_3_B: C3.2, J908.3, R19.1
/Back board/FROM_TANK: IC102.5 (+), J912.2, R106.1, X102.T
/Back board/IN_1: C1.2, J904.T
/Back board/IN_2: C2.2, J905.T
/Back board/MIX: IC103.13 (-), IC103.14, J903.T
/Back board/MIXPOT_BRICK_B: IC103.8, J910.7, R108.2
/Back board/MIXPOT_SPRING_B: C110.2, IC102.7, J910.9, R109.2
/Back board/PWR_GND: U901.2 (GND), Z$102.2 (PWR-GND)
/Back board/REVERB_RETURN: IC102.3 (+), J901.TN, J910.8
/Back board/REVERB_SEND: C5.2, IC102.10 (+), R18.2, R19.2, R101.1, U7.1
/Back board/TO_TANK: C101.1, IC102.9 (-), J911.2, R103.2, X101.T
/Back board/TO_TANK_S_B: C108.1, IC102.8, J911.1, X101.S
/Back board/TRIM_B: C101.2, J910.4
/Back board/VAC_AN_B: J910.5, V101.2 (+)
/Back board/VAC_CA_B: J910.6, V101.1 (-)
/Back board/WET: IC102.1, IC102.2 (-), J905.TN, J906.T
/Back board/XFADE: IC103.3 (+), J901.T
/Front board/AUDIO_IN_1: J907.5, R8.1
/Front board/AUDIO_IN_2: J907.6, RV903.3
/Front board/CV_IN: J907.4, R16.1, RV902.3
/Front board/CV_LEVEL: RV902.2, U2.5 (+)
/Front board/DRY_F: J907.7, R13.2, U1.1
/Front board/EQ_POT_1_F: J907.1, RV904.1
/Front board/EQ_POT_2_F: J907.2, RV904.2
/Front board/EQ_POT_3_F: J907.3, RV904.3
/Front board/FB_LEVEL: R1.1, R26.1, RV903.2, SW901.3
/Front board/MIX: R21.1, RV901.2
/Front board/MIXPOT_BRICK_F: J909.7, RV905.3
/Front board/MIXPOT_SB_MIX_F: J909.8, RV905.2
/Front board/MIXPOT_SPRING_F: J909.9, RV905.1
/Front board/TRIM_F: J909.4, VR1.1
/Front board/VAC_AN_F: J909.5, LED1.1 (K)
/Front board/VAC_CA_F: J909.6, R24.1, U2.2 (-)
GND: C6.2, C7.1, C903.2, C904.1, J907.8, J909.1, R2.2, R12.2, R23.2, R24.2, R25.2, RV901.1, RV902.1, RV903.1, TP905.1, VR1.2, VR1.3
GND_B: C102.2, C103.1, C104.2, C105.1, C106.2, C107.1, C901.1, C902.2, IC102.12 (+), IC103.10 (+), J901.S, J902.S, J903.S, J904.S, J905.S, J906.S, J908.8, J910.1, J912.1, R4.2, R5.2, R102.2, R106.2, R107.2, SJ101.1 (A), SV101.3 (GND), SV101.4 (GND), SV101.5 (GND), SV101.6 (GND), SV101.7 (GND), SV101.8 (GND), TP902.1, U7.3 (+), U7.5 (+), X102.S, Z$102.4 (SIG-GND)
unnamed: C3.1, R10.2
unnamed: C4.2, R18.1
unnamed: C108.2, R103.1
unnamed: C109.1, R107.1
unnamed: C109.2, C110.1, IC102.6 (-), R109.1
unnamed: IC102.13 (-), IC102.14
unnamed: IC103.1, IC103.2 (-), V101.4
unnamed: IC103.6 (-), IC103.7, R110.2
unnamed: IC103.9 (-), R104.2, R105.2, R108.1, SJ101.2 (B)
unnamed: IC103.12 (+), R110.1, V101.3
unnamed: LED1.2 (A), U2.1
unnamed: R7.2, R9.1, U1.7
unnamed: R6.2, R10.1, R11.1, U7.7
unnamed: R20.2, R22.1, U2.7
unnamed: R25.1, R26.2, SW901.1
unnamed: R8.2, R9.2, U1.3 (+)
unnamed: R12.1, R13.1, U1.2 (-)
unnamed: R2.1, SW901.2, U1.5 (+)
unnamed: R1.2, R7.1, U1.6 (-)
unnamed: R21.2, R22.2, R23.1, U2.3 (+)
unnamed: R16.2, R20.1, U2.6 (-)
unnamed: R3.2, R6.1, U7.6 (-)
unnamed: R101.2, R102.1, Z$102.3 (INPUT)
unnamed: R104.1, Z$102.6 (OUT1)
unnamed: R105.1, Z$102.5 (OUT2)

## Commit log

2022-06-11 Initial version
    [back.kicad_sch, front.kicad_sch, springReverbRev2.kicad_pcb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]
2022-06-12 Note on phono jacks, replace pin headers with Molex
    [back.kicad_sch, springReverbRev2.kicad_pcb, springReverbRev2.kicad_sch]
2022-06-12 Layout redone
    [back.kicad_sch, front.kicad_sch, springReverbRev2.kicad_pcb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]
2022-06-12 phono jacks
    [back.kicad_sch, springReverbRev2.kicad_pcb, springReverbRev2.kicad_sch]
2022-06-14 Reorg folders
    [Spring_Rev2_expander.kicad_pcb, Spring_Rev2_expander.kicad_sch, back.kicad_sch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]
2022-09-22 Schem tidying
    [front.kicad_sch]
2022-11-12 misc corrections
    [back.kicad_sch, front.kicad_sch, springReverbRev2.kicad_pcb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]
2023-02-16 Bigger tone knob; hardware
    [back.kicad_sch, front.kicad_sch, springReverbRev2.kicad_pcb]
2023-03-08 rm expander, reorg PCB folder
    [Spring_Rev2_expander.kicad_pcb, Spring_Rev2_expander.kicad_sch, back.kicad_sch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]
2023-03-17 PCB revisions, Docs
    [back.kicad_sch, front.kicad_sch, panelmount.kicad_sch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]
2023-03-29 Restore R4 and R5 references; change C1 and C2 values; mark R5 to omit; README list of changes
    [back.kicad_sch, springReverbRev2.kicad_pcb, springReverbRev2.kicad_sch]
2023-05-05 Docs; make LED position consistent
    [back.kicad_sch, front.kicad_sch, springReverbRev2.kicad_pcb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]
2023-05-05 Use open not bridged jumper
    [back.kicad_sch, springReverbRev2.kicad_pcb]
2023-05-06 Correct mix pot label
    [springReverbRev2.kicad_pcb, springReverbRev2_panel.kicad_pcb]
2023-05-17 Ungrounded jack for tank send
    [springReverbRev2_panel.kicad_pcb, springReverbRev2_panel.kicad_sch]
2023-05-18 Ungrounded jack
    [springReverbRev2_panel.kicad_pcb, springReverbRev2_panel.kicad_sch]

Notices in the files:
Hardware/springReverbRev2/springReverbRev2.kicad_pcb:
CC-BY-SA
